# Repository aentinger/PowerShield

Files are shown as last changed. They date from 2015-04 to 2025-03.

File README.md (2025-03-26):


💾 Power Shield
===============



# 📸 Image

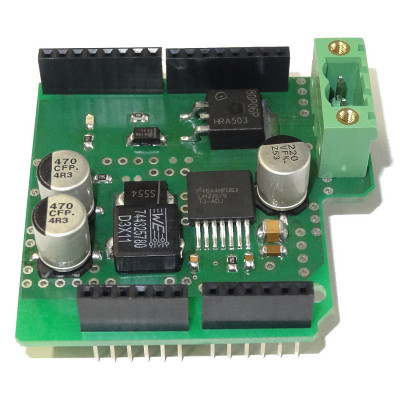
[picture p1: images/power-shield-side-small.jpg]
LXRobotics P16 PowerShield


# 📂 Description

The LXRobotics Power Shield facilitates the high power supply of an Arduino Board over a wide input voltage range. Furthermore, the Power Shield allows the usage of Shields with high power requirements, which can not be supplied solely by the linear regulator of the Arduino (such as the Servo Shield when connecting 18 servos). A reverse polarity protection protects the Power Shield against destruction caused by faulty connections of the input voltage.

**Features**

* High power supply over wide input voltage rande 6 - 24 V DC
* Allows usage of Shields with high power requirements ()
* Reverse polarity protection
* Status-LED
* High-quality pluggable screw terminals for easy and stable connection of the supply

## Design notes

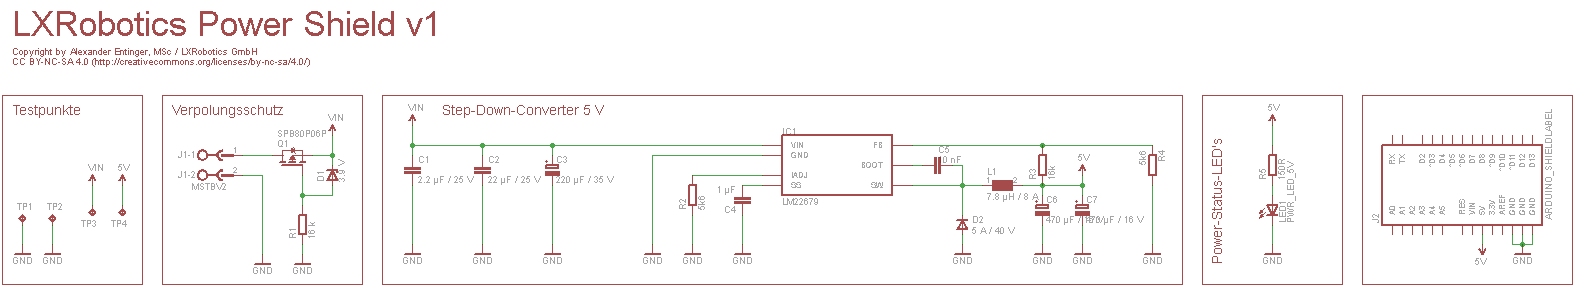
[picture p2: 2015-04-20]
hardware/lxr_power_shield_v1.png

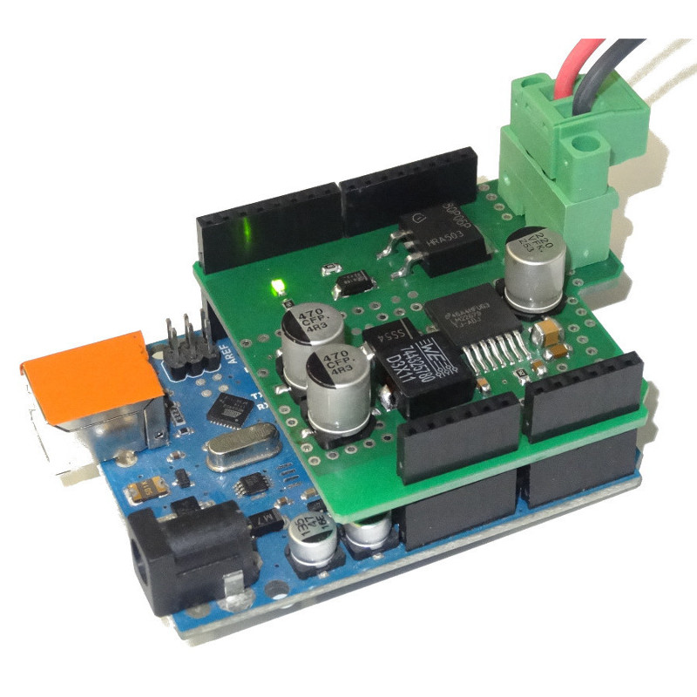
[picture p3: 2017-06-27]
images/power-shield-action-large.jpg

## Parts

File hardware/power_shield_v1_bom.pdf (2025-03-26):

Menge | Schaltplan | Bezeichnung | Farnell Bestell Nummer | Preis (1 Stück) | Gesamtpreis | Wird bestückt | Footprint | Säckchen
1 | C1 | 2.2 µF / 25 V / 1206 | 1759451 | € 0,06 | € 0,06 | X
1 | C2 | 22 µF / 25 V / 1210 | 2320935 | € 0,70 | € 0,70 | X
1 | C3 | 220 µF / 35 V / Panasonic F | 9695877 | € 0,57 | € 0,57 | X
1 | C4 | 1 µF / 25 V / 0805 | 9406395 | € 0,09 | € 0,09 | X
1 | C5 | 10 nF / 0805 | 1856461 | € 0,05 | € 0,05 | X
2 | C6,C7 | 470 µF / 16 V / Panasonic F | 1539508 | € 0,73 | € 1,46 | X
1 | D1 | Z-Diode / 3,9V / SMB | 1459010 | € 0,31 | € 0,31 | X
1 | D2 | 5 A / 40 V / Schottky / SMC | 1861427 | € 0,16 | € 0,16 | X
1 | IC1 | LM22679 | 1657731 | € 3,45 | € 3,45 | X
1 | J1 | Stiftleiste / 5,08 mm / 2-Polig | 1792792 | € 1,94 | € 1,94 | | | S1
1 | J1 | Kabelstecker 90° / 5,08 mm / 2-Polig | 1792832 | € 1,51 | € 1,51 | | | S1
1 | L1 | 7,8 µH / 8 A | 2211623 | € 3,80 | € 3,80 | X
1 | LED1 | SMD-LED, Grün, 0805, If=20 mA, Uf=2.1 | 1519498 | € 0,24 | € 0,24 | X
1 | Q1 | P-Kanal-MOSFET / -80 A / -60 V / TO263 | 2212850 | € 3,71 | € 3,71 | X
1 | R1,R3 | 16k / 0805 | 2073652 | € 0,02 | € 0,02 | X
2 | R2,R4 | 5k6 / 0805 | 9334696 | € 0,01 | € 0,01 | X
1 | R5 | 150R / 0805 | 9333916 | € 0,04 | € 0,04 | X
1 | J2 | Satz Arduino Buchsenleisten | ELV | € | 0,75 | € | 0,75 | S2 | http://www.elv.at/buchsenleisten-set-fuer-arduino-boards.html
| | | | Summe | | € | 18,88

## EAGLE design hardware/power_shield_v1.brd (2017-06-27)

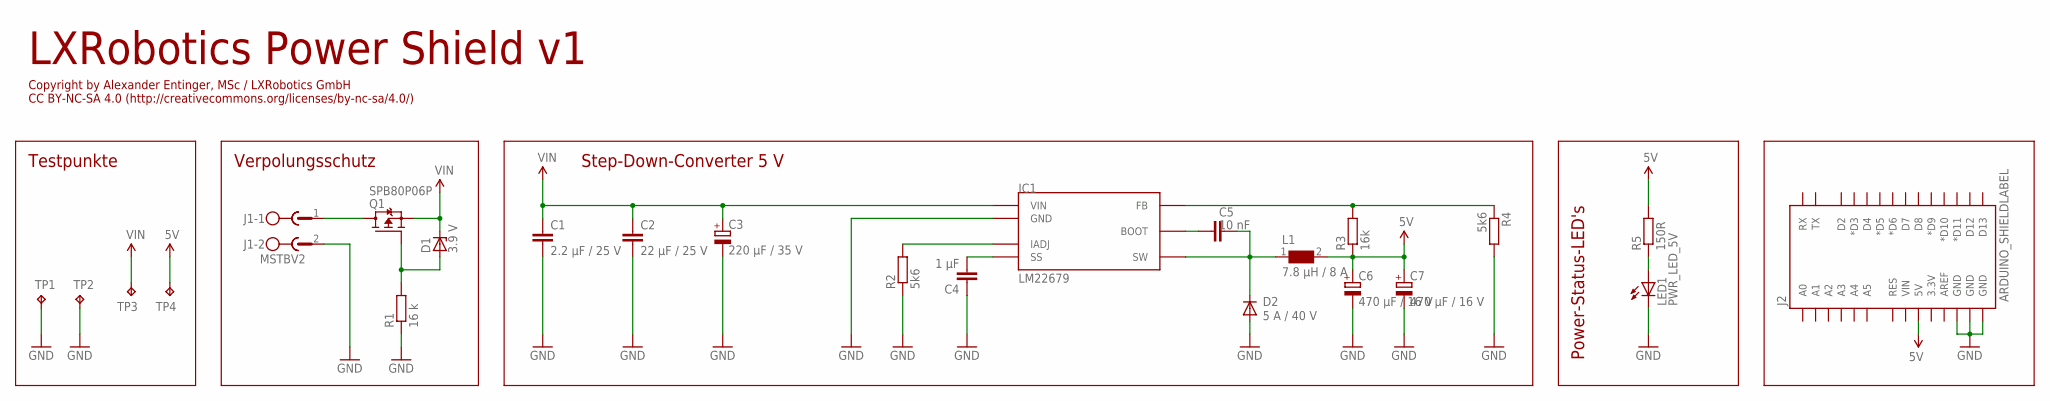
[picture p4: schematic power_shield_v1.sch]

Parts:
C1: 2.2 µF / 25 V; C1206
C2: 22 µF / 25 V; C1210
C3: 220 µF / 35 V; PANASONIC_F
C4: 1 µF; C0805
C5: 10 nF; C0805
C6, C7: 470 µF / 16 V; PANASONIC_F
D1: 3.9 V; SMB
D2: 5 A / 40 V; SMC
IC1: LM22679; P-TO263-7-1
J1: MSTBV2
J2: ARDUINO_SHIELDLABEL; DUEMILANOVE_SHIELD
L1: 7.8 µH / 8 A; WE-HCI_1050
LED1: PWR_LED_5V; CHIPLED_0805
Q1: SPB80P06P; TO263
R1: 16 k; M0805
R2, R4: 5k6; M0805
R3: 16k; M0805
R5: 150R; M0805
TP1, TP2, TP3, TP4: TPB1,27; B1,27

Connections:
5V: C6.+, C7.+, J2.5V, L1.2, R3.1, R5.2, TP4.TP
GND: C1.2, C2.2, C3.-, C4.1, C6.-, C7.-, D2.A, IC1.4 (GND), IC1.TH (GND), J1.2, J2.GND@0 (GND), J2.GND@1 (GND), J2.GND@2 (GND), LED1.C, R1.1, R2.1, R4.2, TP1.TP, TP2.TP
unnamed: IC1.5 (IADJ), R2.2
unnamed: C4.2, IC1.7 (SS)
unnamed: IC1.6 (FB), R3.2, R4.1
unnamed: C5.1, IC1.3 (BOOT)
unnamed: C5.2, D2.C, IC1.1 (SW), L1.1
unnamed: LED1.A, R5.1
unnamed: D1.A, Q1.1 (G), R1.2
unnamed: J1.1, Q1.3 (D)
VIN: C1.1, C2.1, C3.+, D1.C, IC1.2 (VIN), Q1.2 (S), TP3.TP

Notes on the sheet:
Verpolungsschutz
Testpunkte
LXRobotics Power Shield v1
Step-Down-Converter 5 V
Power-Status-LED's
Copyright by Alexander Entinger, MSc / LXRobotics GmbH CC BY-NC-SA 4.0 (http://creativecommons.org/licenses/by-nc-sa/4.0/)

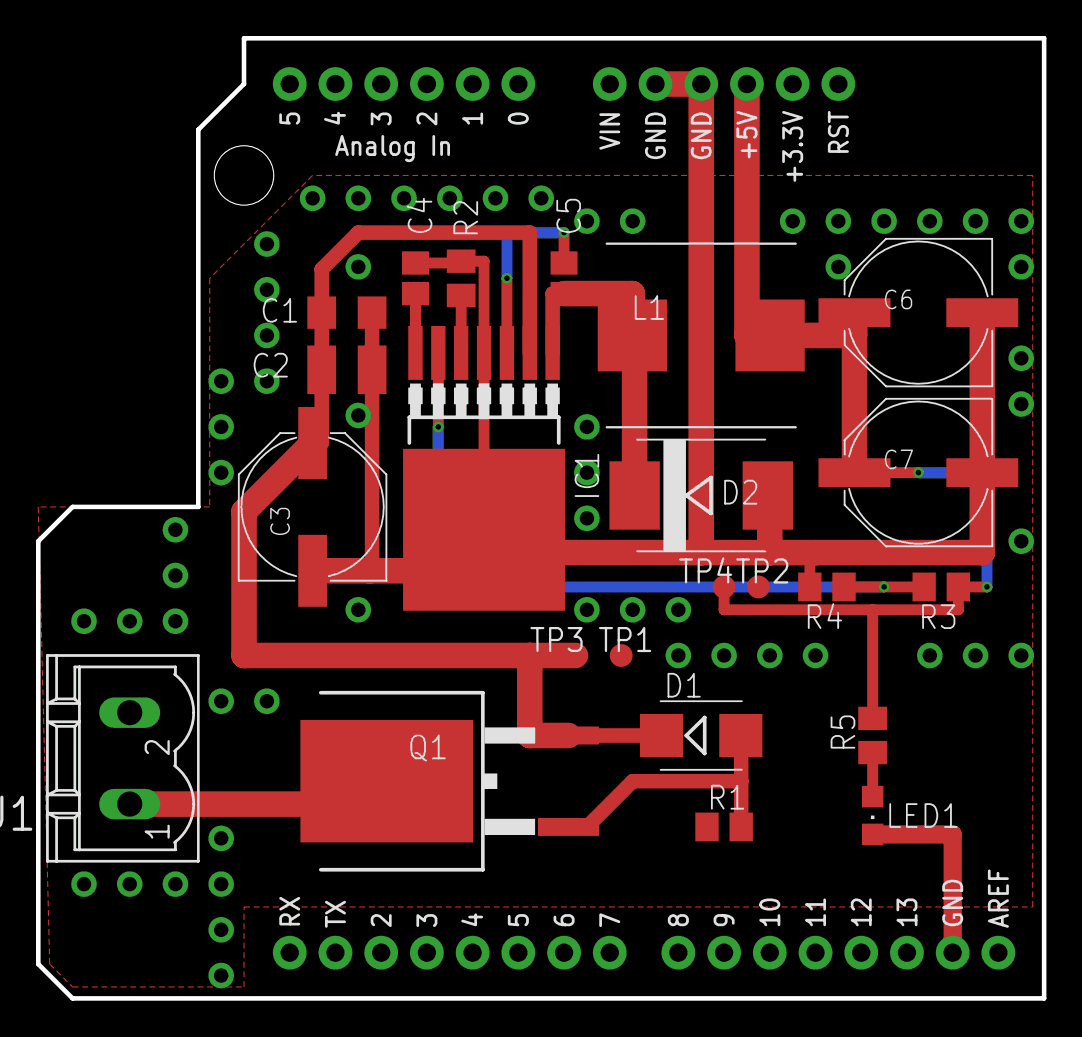
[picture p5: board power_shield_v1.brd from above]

Board: 2 copper layers, 55.9 x 53.3 mm, 24 parts (0 on the bottom side), 11 nets.

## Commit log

2015-04-20 adding readme and schematic
2017-06-27 Adding hardware + images
    [power_shield_v1.brd, power_shield_v1.sch]
2025-03-26 Uploading BOM.

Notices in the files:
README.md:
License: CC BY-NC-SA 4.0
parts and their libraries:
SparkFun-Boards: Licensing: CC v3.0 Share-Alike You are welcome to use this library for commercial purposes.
